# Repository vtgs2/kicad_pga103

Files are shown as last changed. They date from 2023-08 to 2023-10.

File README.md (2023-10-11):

# kicad_pga103

KiCAD Designs for PGA-103+ Preamplifier (LNA) intended for use in VHF / UHF Satellite Reception.  

This is a catchall repo for multiple designs and multiple variants.  
The variants will be based on physical size, enclosure dimensions, and specific features.  
This is a fluid repo that wil be changing as time allows to include updates for parts selection and user guide for how to configure for different bands.  

## Shut up and give me the board

Completed Designs:
- v2.0.0.0, rev-, Oct 2, 2023
- v2.1.X.0, rev-, Oct 2, 2023
- v2.2.X.0, rev-, Oct 2, 2023

#### Osh Park:
[v2.0.0.0, rev-](https://oshpark.com/shared_projects/KYiMNU72)  
[v2.1.X.0, rev-](https://oshpark.com/shared_projects/wypFvs1c)  
[v2.2.X.0, rev-](https://oshpark.com/shared_projects/yOYgdtt8)  

## Major Design Features

### Active Device
Primary active device is the popular [PGA-103+](https://www.minicircuits.com/WebStore/dashboard.html?model=PGA-103%2B).
Expect >20 dB Gain and <1.0 dB Noise Figure for both VHF and UHF bands.  

### Bias Options
Multiple biasing options via solder jumpers on the board.  
See board silkscreen for solder jumper settings for selecting the methods described below.

#### DC on Coax, +12V
The primary expected method for powering the board.  
This method routes DC power from the output RF connector to the internal voltage regulator for power conditioning, filtering, and biasing the amp.  
A bias-t will be required on the other end of the coax close to the radio.  
A custom Bias-T design may be added to this repo, but for now here are some COTS options:
- Minicircuits [ZDPLX-2150-S+](https://www.minicircuits.com/WebStore/dashboard.html?model=ZDPLX-2150-S%2B) where the Low Pass port is for DC. Be careful about current draw requirements if using long coax runs as this has a fairly low current limit of about 100mA.  Have succesfully used this on multiple compact systems in the past.
- Minicircuits [ZABT-2R15G+](https://www.minicircuits.com/WebStore/dashboard.html?model=ZABT-2R15G%2B). This Bias-T allows 3A of DC current and also includes ability to inject a 10 MHz reference signal (not needed for this specific preamp design, but might be useful for future projects for distributing REF oscillator signals to antenna mounted components such as downconverters).
- [Kuhne Electronic Bias-Ts](https://www.kuhne-electronic.com/funk/en/shop/industrial/prof-passive-compone/prof-bias-tees/).  Pricey, but work well. They offer N and SMA variants.

##### Lightning Arrestors
If using the DC on coax methods and if using lightning arrestors (you should be!), be sure to select arrestors that allow DC pass through.  I typically connect bias-ts directly to the lightning arrestors inside the enclosure on the 'equipment' side of the arrestor using barrel N or SMA connectors.

#### DC on Coax, Direct 5V
DC on coax can be routed to AVOID the onboard voltage regulator and directly bias the PGA-103+ device.  
This method may be suitable for SDRs that have built in Bias-Ts, such as the popular [RTL-SDR](https://www.rtl-sdr.com/buy-rtl-sdr-dvb-t-dongles/) that has a built in 4.5V bias-T.

#### External DC
This method does not interact with RF output connector and supplies power to the onboard voltage regulator.  
The supplied DC Voltage should be between 6V and 16V as measured at the board input pads (consider DC voltage drop if running long external power lines).  
The current mechanical designs for enclosure do not include penetrations for external power.  
If adding external power, feed through capacitors / EMI filters are recommended. Something like [this](https://www.digikey.com/en/products/detail/tusonix-a-subsidiary-of-cts-electronic-components/4400-034LF/2079728).

## Version Description
Versioning is inspired by MAJOR.MINOR.PATCH type versioning....but will also be breaking the rules for that on purpose.

Version Fields:  ENCLOSURE.FILTER.BAND.GAIN
##### ENCLOSURE:  
1.X.X.X  [1550Z101](https://www.digikey.com/en/products/detail/hammond-manufacturing/1550Z101/2268541)  
2.X.X.X  [AN-1301-A](https://www.digikey.com/en/products/detail/bud-industries/AN-1301-A/5804533)

Enclosure style essentially dictates the board outline.

##### FILTER Style:  
X.0.X.X  No Filter  
X.1.X.X  [RBP-XXX Filter](https://www.minicircuits.com/WebStore/dashboard.html?model=RBP-140%2B)  
X.2.X.X  [SBXP-XXX Filter](https://www.minicircuits.com/WebStore/dashboard.html?model=SXBP-140%2B)

##### BAND:   
X.X.0.X  Wideband  
X.X.1.X  VHF  
X.X.2.X  UHF  

Band selection depends on the filter selection and the choice of components for the bypass caps and bias-t inductors.

##### GAIN:   
X.X.X.0  Single Stage  
X.X.X.1  Dual Stage  

Curent completed designs only include the single gain stage preamplifiers.
Future designs may include a dual gain stage design for 'ultra-gain' type operation.

<!-- | Version | Enclosure  | Filter    | Description  | Design Complete |
| ------- | ---------- | --------- | ------------ | --------------- |
| 1.0.0   | 1550Z102   | False     |              | True |
| 1.1.X   | 1550Z102   | RBP-XXX   |              | True |
| 1.1.1   | 1550Z102   | RBP-140   | VHF Band     | True |
| 1.1.2    | 1550Z102   | RBP-440   | UHF Band     | True |
| 2.0.0.0 | AN-1301-A  | False     | Alt Encl: 1550Z104  | False |
| 2.1.X   | AN-1301-A  | RBP-XXX   |              | False |
| 2.1.1   | AN-1301-A  | RBP-140   | VHF Band     | False |
| 2.1.2   | AN-1301-A  | RBP-440   | UHF Band     | False |
| 2.2.X   | AN-1301-A  | SBXP-XXX  |              | False |
| 2.2.1   | AN-1301-A  | SBXP-140  | VHF Band     | False |
| 2.2.2   | AN-1301-A  | SBXP-440  | UHF Band     | False | -->

<!-- 

Multiple variants:
- Version 1: Unfiltered
- Version 2: Mini Circuits RBP-XXX Bandpass Filter
- Version 3: Mini Circuits SXBP-XXX Bandpass Filter
- Version 4: Dual Gain, RBP-XXX (Future)
- Version 5: Dual Gain, SXBP-XXX (Future) -->

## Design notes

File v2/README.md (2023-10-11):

# PGA-103+ Preamplifier, Version 2

Enclosure: AN-1301-A

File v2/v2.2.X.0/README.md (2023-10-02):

# PGA-103+ Preamplifier, Version 2.2.X.0

Enclosure: AN-1301-A  
Filter: SXBP-XXX  
Band: VHF or UHF  
Gain: Single Stage

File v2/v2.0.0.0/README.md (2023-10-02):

# PGA-103+ Preamplifier, Version 2.0.0.0

Enclosure: AN-1301-A  
Filter: None  
Band: Wideband  
Gain: Single Stage

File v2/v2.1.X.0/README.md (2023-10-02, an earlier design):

# PGA-103+ Preamplifier, Version 2.1.X.0

Enclosure: AN-1301-A  
Filter: RBP-XXX  
Band: VHF or UHF  
Gain: Single Stage

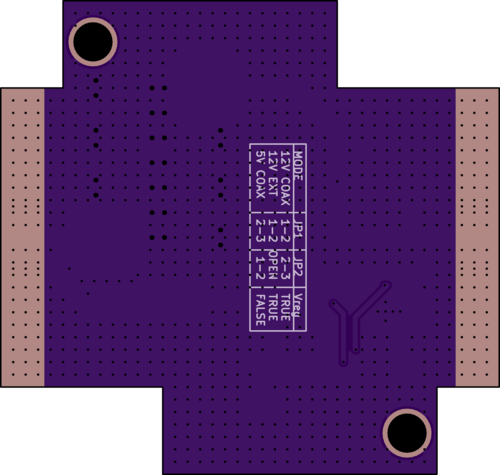
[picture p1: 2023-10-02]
v2/v2.2.X.0/rev-/osh_park_bottom_view.png

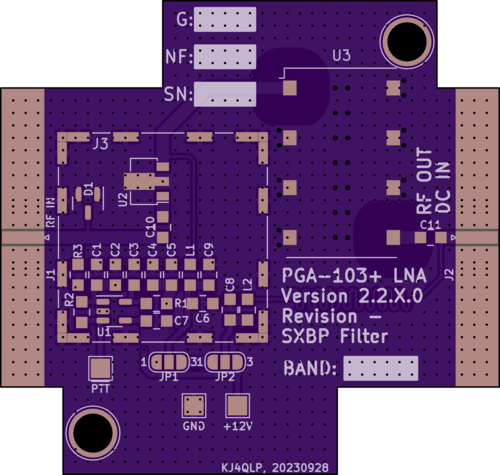
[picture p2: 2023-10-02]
v2/v2.2.X.0/rev-/osh_park_top_view.png

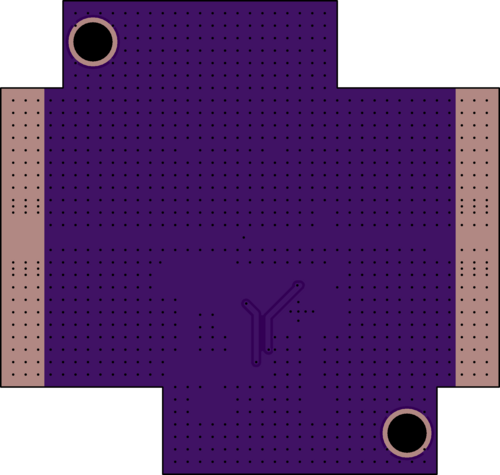
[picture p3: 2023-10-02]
v2/v2.0.0.0/rev-/osh_park_bottom_view.png

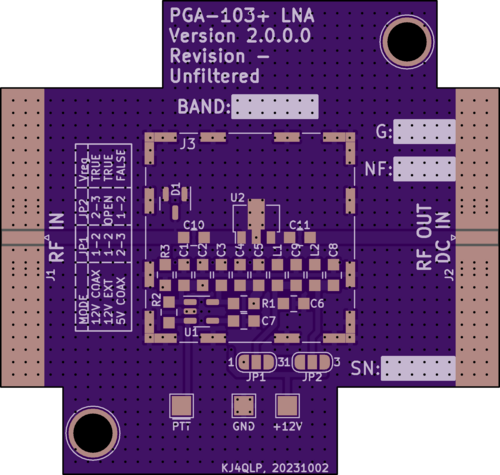
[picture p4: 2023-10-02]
v2/v2.0.0.0/rev-/osh_park_top_view.png

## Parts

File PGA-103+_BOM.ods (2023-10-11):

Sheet: MASTER_PGA-103
Supplier | Part # | Supplier Description | U/L | Qty | Unit Cost | Total Cost | LINK | Board ID | Comment | Order Status
Digikey | 3157-PGA-103+CT-ND | RF Amplifier IC CATV, Cellular, DBS, MMDS, PCS, WLAN, Wireless LAN 50MHz ~ 4GHz SOT-89 | ea | 10 | $2.63 | $26.30 | LINK (https://www.digikey.com/en/products/detail/mini-circuits/PGA-103/13680582?s=N4IgTCBcDaIAoHECCBaAjABgMwgLoF8g)
Digikey | 732-2486-ND | RF Shield Frame 0.827" (21.00mm) X 0.827" (21.00mm) Surface Mount | ea | 10 | $3.18 | $31.80 | LINK (https://www.digikey.com/en/products/detail/würth-elektronik/36103205/2337461)
Digikey | 1016-1874-1-ND | SPX3819M5-L-5-0/TR; Linear Voltage Regulator IC Positive Fixed 1 Output 500mA SOT-23-5; 5V | ea | 10 | $0.50 | $5.00 | LINK (https://www.digikey.com/en/products/detail/maxlinear-inc/SPX3819M5-L-5-0-TR/2472395)
Digikey | 3157-RBP-140+CT-ND | RBP-140+, 140MHz Center Frequency Band Pass RF Filter (Radio Frequency) 20MHz Bandwidth 3.5dB 8-SMD, No Lead | ea | 1 | $19.90 | $19.90 | LINK (https://www.digikey.com/en/products/detail/mini-circuits/RBP-140/13927413?s=N4IgTCBcDaIEoCEAKBaAjAFgAwgLoF8g) | V2.1.1.0
Digikey | 3157-RBP-440+CT-ND | RBP-440+, 440MHz Center Frequency Band Pass RF Filter (Radio Frequency) 60MHz Bandwidth 8-SMD, No Lead | ea | 1 | $18.56 | $18.56 | LINK (https://www.digikey.com/en/products/detail/mini-circuits/RBP-440/13928394?s=N4IgTCBcDaIEoCEAKBaALGgDCAugXyA) | V2.1.2.0
Minicircuits | SXBP-140+ | SXBP-140+, Lumped LC Band Pass Filter, 130 - 150 MHz, 50Ω | ea | 1 | $20.17 | $20.17 | LINK (https://www.minicircuits.com/WebStore/dashboard.html?model=SXBP-140%2B) | V2.2.1.0
Minicircuits | SXBP-425+ | SXBP-425+, Lumped LC Band Pass Filter, 410 - 440 MHz, 50Ω | ea | 1 | $22.70 | $22.70 | LINK (https://www.minicircuits.com/WebStore/dashboard.html?model=SXBP-425%2B) | V2.2.2.0
Digikey | 490-18663-1-ND | 10 µF ±10% 50V Ceramic Capacitor X5R 0805 (2012 Metric) | ea | 10 | $0.21 | $2.09 | LINK (https://www.digikey.com/en/products/detail/murata-electronics/GRM21BR61H106KE43L/10326316)
Digikey | 478-KGM21AR71H105JUCT-ND | 1 µF ±5% 50V Ceramic Capacitor X7R 0805 (2012 Metric) | ea | 25 | $0.22 | $5.48 | LINK (https://www.digikey.com/en/products/detail/kyocera-avx/KGM21AR71H105KU/3081236)
Digikey | 478-KGM21NR71H104JTCT-ND | 0.1 µF ±5% 50V Ceramic Capacitor X7R 0805 (2012 Metric) | ea | 100 | $0.04 | $3.78 | LINK (https://www.digikey.com/en/products/detail/kyocera-avx/KGM21NR71H104JT/929984)
Digikey | 478-08052C102J4Z2ACT-ND | 1000 pF ±5% 200V Ceramic Capacitor X7R 0805 (2012 Metric) | ea | 100 | $0.05 | $4.80 | LINK (https://www.digikey.com/en/products/detail/kyocera-avx/KAF21BR72D102JT/11238727) |  | For VHF
Digikey | 478-10451-1-ND | 330 pF ±5% 200V Ceramic Capacitor X7R 0805 (2012 Metric) | ea | 100 | $0.05 | $5.01 | LINK (https://www.digikey.com/en/products/detail/kyocera-avx/08052C331JAZ2A/6138434) |  | For UHF
Digikey | 13-RC0805FR-10100KLCT-ND | 100 kOhms ±1% 0.125W, 1/8W Chip Resistor 0805 (2012 Metric) Moisture Resistant Thick Film | ea | 100 | $0.01 | $1.27 | LINK (https://www.digikey.com/en/products/detail/yageo/RC0805FR-10100KL/13694085)
Digikey | 311-2.94CRCT-ND | 2.94 Ohms ±1% 0.125W, 1/8W Chip Resistor 0805 (2012 Metric) Moisture Resistant Thick Film | ea | 10 | $0.04 | $0.41 | LINK (https://www.digikey.com/en/products/detail/yageo/RC0805FR-072R94L/727716) |  | For 4.75V bias @ 84.9mA
Digikey | 311-1.50CRCT-ND | 1.5 Ohms ±1% 0.125W, 1/8W Chip Resistor 0805 (2012 Metric) Moisture Resistant Thick Film | ea | 100 | $0.02 | $2.27 | LINK (https://www.digikey.com/en/products/detail/yageo/RC0805FR-071R5L/727495) |  | to account for inductor resistance, 330nH
Digikey | 311-2.26CRTR-ND | 2.26 Ohms ±1% 0.125W, 1/8W Chip Resistor 0805 (2012 Metric) Moisture Resistant Thick Film | ea | 100 | $0.03 | $2.68 | LINK (https://www.digikey.com/en/products/detail/yageo/RC0805FR-072R26L/727681) |  | to account for inductor resistance, 220nH
Digikey | 490-5672-1-ND | 330 nH Unshielded Wirewound Inductor 310 mA 1.4Ohm Max 0805 (2015 Metric) | ea | 25 | $0.16 | $3.95 | LINK (https://www.digikey.com/en/products/detail/murata-electronics/LQW2BASR33J00L/2625457) |  | 1.4Ohm res, for VHF
Digikey | 490-5669-1-ND | FIXED IND 220NH 400MA 700MOHM SM | ea | 25 | $0.16 | $3.95 | LINK (https://www.digikey.com/en/products/detail/murata-electronics/LQW2BASR22J00L/2625454) |  | 0.7 Ohm, for UHF
Digikey | 377-2390-ND | Box Metal, Aluminum Natural Cover Included 2.520" L x 2.270" W (64.01mm x 57.66mm) X 1.378" (35.00mm) | ea | 6 | $7.10 | $42.60 | LINK (https://www.digikey.com/en/products/detail/bud-industries/AN-1301-A/5804533) | V2 | Bud industries alternative
Digikey | 36-909-ND | 4 Stud Lockwasher, Internal Tooth Lug Terminal Flat Connector | ea | 25 | $0.19 | $4.86 | LINK (https://www.digikey.com/en/products/detail/keystone-electronics/909/317250)
Digikey | ACX1165-ND | N Type Connector Receptacle, Female Socket 50 Ohms Panel Mount Solder | ea | 12 | $6.45 | $77.41 | LINK (https://www.digikey.com/en/products/detail/amphenol-rf/172117/1011842)
McMaster-Carr | 92196A110 | 18-8 Stainless Steel Socket Head Screw, 4-40 Thread Size, 1/2" Long | pk | 1 | $6.38 | $6.38 | LINK (https://www.mcmaster.com/92196A110/)
McMaster-Carr | 91841A005 | 18-8 Stainless Steel Hex Nut, 4-40 Thread Size | pk | 1 | $3.89 | $3.89 | LINK (https://www.mcmaster.com/91841A005/)
 |  |  |  |  |  | $0.00
 |  |  |  |  | Subtotal | $315.26
Digikey | HM180-ND | Box Metal, Aluminum Unpainted Cover Included 1.976" L x 1.780" W (51.19mm x 45.21mm) X 1.197" (30.40mm) | ea | 0 | $8.46 | $0.00 | LINK (https://www.digikey.com/en/products/detail/hammond-manufacturing/1550Z101/2268541) | V1 | 6 in stock
Digikey | HM181-ND | Box Metal, Aluminum Black Cover Included 1.976" L x 1.780" W (51.19mm x 45.21mm) X 1.197" (30.40mm) | ea | 0 | $12.05 | $0.00 | LINK (https://www.digikey.com/en/products/detail/hammond-manufacturing/1550Z101BK/2268542) | V1 | alternative to above, 12 in stock
Digikey | HM186-ND | Box Metal, Aluminum Unpainted Cover Included 2.535" L x 2.299" W (64.39mm x 58.39mm) X 1.394" (35.41mm) | ea | 0 | $9.39 | $0.00 | LINK (https://www.digikey.com/en/products/detail/hammond-manufacturing/1550Z104/2268547) | V2
Digikey | 501-1549-ND | Box Metal, Aluminum Unpainted Cover Included 1.500" L x 1.130" W (38.10mm x 28.70mm) X 0.880" (22.35mm) | ea | 0 | $9.99 | $0.00 | LINK (https://www.digikey.com/en/products/detail/pomona-electronics/3754/736549) |  | Pomona tiny box, Bias-T candidate
Digikey | ARF2999-ND | N Type Connector Receptacle, Male Pin 50 Ohms Panel Mount Solder | ea | 0 | $12.07 | $0.00 | LINK (https://www.digikey.com/en/products/detail/amphenol-rf/172260/4948205)

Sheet: digikey_upload
3157-PGA-103+CT-ND | RF Amplifier IC CATV, Cellular, DBS, MMDS, PCS, WLAN, Wireless LAN 50MHz ~ 4GHz SOT-89 | 10 | $2.63
732-2486-ND | RF Shield Frame 0.827" (21.00mm) X 0.827" (21.00mm) Surface Mount | 10 | $3.18
1016-1874-1-ND | SPX3819M5-L-5-0/TR; Linear Voltage Regulator IC Positive Fixed 1 Output 500mA SOT-23-5; 5V | 10 | $0.50
3157-RBP-140+CT-ND | RBP-140+, 140MHz Center Frequency Band Pass RF Filter (Radio Frequency) 20MHz Bandwidth 3.5dB 8-SMD, No Lead | 1 | $19.90
3157-RBP-440+CT-ND | RBP-440+, 440MHz Center Frequency Band Pass RF Filter (Radio Frequency) 60MHz Bandwidth 8-SMD, No Lead | 1 | $18.56
490-18663-1-ND | 10 µF ±10% 50V Ceramic Capacitor X5R 0805 (2012 Metric) | 10 | $0.21
478-KGM21AR71H105JUCT-ND | 1 µF ±5% 50V Ceramic Capacitor X7R 0805 (2012 Metric) | 25 | $0.22
478-KGM21NR71H104JTCT-ND | 0.1 µF ±5% 50V Ceramic Capacitor X7R 0805 (2012 Metric) | 100 | $0.04
478-08052C102J4Z2ACT-ND | 1000 pF ±5% 200V Ceramic Capacitor X7R 0805 (2012 Metric) | 100 | $0.05
478-10451-1-ND | 330 pF ±5% 200V Ceramic Capacitor X7R 0805 (2012 Metric) | 100 | $0.05
13-RC0805FR-10100KLCT-ND | 100 kOhms ±1% 0.125W, 1/8W Chip Resistor 0805 (2012 Metric) Moisture Resistant Thick Film | 100 | $0.01
311-2.94CRCT-ND | 2.94 Ohms ±1% 0.125W, 1/8W Chip Resistor 0805 (2012 Metric) Moisture Resistant Thick Film | 10 | $0.04
311-1.50CRCT-ND | 1.5 Ohms ±1% 0.125W, 1/8W Chip Resistor 0805 (2012 Metric) Moisture Resistant Thick Film | 100 | $0.02
311-2.26CRTR-ND | 2.26 Ohms ±1% 0.125W, 1/8W Chip Resistor 0805 (2012 Metric) Moisture Resistant Thick Film | 100 | $0.03
490-5672-1-ND | 330 nH Unshielded Wirewound Inductor 310 mA 1.4Ohm Max 0805 (2015 Metric) | 25 | $0.16
490-5669-1-ND | FIXED IND 220NH 400MA 700MOHM SM | 25 | $0.16
377-2390-ND | Box Metal, Aluminum Natural Cover Included 2.520" L x 2.270" W (64.01mm x 57.66mm) X 1.378" (35.00mm) | 6 | $7.10
36-909-ND | 4 Stud Lockwasher, Internal Tooth Lug Terminal Flat Connector | 25 | $0.19
ACX1165-ND | N Type Connector Receptacle, Female Socket 50 Ohms Panel Mount Solder | 12 | $6.45

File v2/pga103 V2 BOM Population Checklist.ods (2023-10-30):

Populated |  |  | V2.0.0.0, Unfiltered
1 | 2 | 3 | Value | Qnty | Cmp name | Ref | Note
 |  |  | 1.0uF | 2 | C | C1, C5
 |  |  | 0.1uF | 4 | C | C2, C3, C6, C7
 |  |  | 10uF | 1 | C | C4
 |  |  | 1000pF (VHF) / 330pF (UHF) | 4 | C | C8, C9, C10, C11 | Double Check VHF/UHF Selection
 |  |  | 330nH (VHF) / 220nH (UHF) | 2 | L | L1, L2 | Double Check VHF/UHF Selection
 |  |  | 10 | 1 | R_US | R1 | Double check value for desired bias point
 |  |  | 100k | 1 | R_US | R2
 |  |  | DNP | 1 | R_US | R3 | Optional Static Bleed, 1 Mohm
 |  |  | BAV99 | 1 | BAV99 | D1 | Optional ESD Protection
 |  |  | RFShield_TwoPieces | 1 | RFShield_TwoPieces | J3
 |  |  | SPX3819M5-L-5-0 | 1 | SPX3819M5-L-5-0 | U1
 |  |  | PGA-103 | 1 | PGA-103 | U2
Populated |  |  | V2.1.0.0, RBP-XXX Filter
1 | 2 | 3 | Value | Qnty | Cmp name | Ref | Note
 |  |  | 1.0uF | 2 | C | C1, C5
 |  |  | 0.1uF | 4 | C | C2, C3, C6, C7
 |  |  | 10uF | 1 | C | C4
 |  |  | 1000pF (VHF) / 330pF (UHF) | 4 | C | C8, C9, C10, C11 | Double Check VHF/UHF Selection
 |  |  | 330nH (VHF) / 220nH (UHF) | 2 | L | L1, L2 | Double Check VHF/UHF Selection
 |  |  | 10 | 1 | R_US | R1 | Double check value for desired bias point
 |  |  | 100k | 1 | R_US | R2
 |  |  | DNP | 1 | R_US | R3 | Optional Static Bleed, 1 Mohm
 |  |  | BAV99 | 1 | BAV99 | D1 | Optional ESD Protection
 |  |  | RFShield_TwoPieces | 1 | RFShield_TwoPieces | J3
 |  |  | SPX3819M5-L-5-0 | 1 | SPX3819M5-L-5-0 | U1
 |  |  | PGA-103 | 1 | PGA-103 | U2
 |  |  | RBP-140/440 | 1 | RBP-280 | U3 | Double Check VHF/UHF Selection
Populated |  |  | V2.2.0.0, SXBP-XXX Filter
1 | 2 | 3 | Value | Qnty | Cmp name | Ref | Note
 |  |  | 1.0uF | 2 | C | C1, C5
 |  |  | 0.1uF | 4 | C | C2, C3, C6, C7
 |  |  | 10uF | 1 | C | C4
 |  |  | 1000pF (VHF) / 330pF (UHF) | 4 | C | C8, C9, C10, C11 | Double Check VHF/UHF Selection
 |  |  | 330nH (VHF) / 220nH (UHF) | 2 | L | L1, L2 | Double Check VHF/UHF Selection
 |  |  | 10 | 1 | R_US | R1 | Double check value for desired bias point
 |  |  | 100k | 1 | R_US | R2
 |  |  | DNP | 1 | R_US | R3 | Optional Static Bleed, 1 Mohm
 |  |  | BAV99 | 1 | BAV99 | D1 | Optional ESD Protection
 |  |  | RFShield_TwoPieces | 1 | RFShield_TwoPieces | J3
 |  |  | SPX3819M5-L-5-0 | 1 | SPX3819M5-L-5-0 | U1
 |  |  | PGA-103 | 1 | PGA-103 | U2
 |  |  | SXBP-140/440 | 1 | SXBP-140 | U3 | Double Check VHF/UHF Selection

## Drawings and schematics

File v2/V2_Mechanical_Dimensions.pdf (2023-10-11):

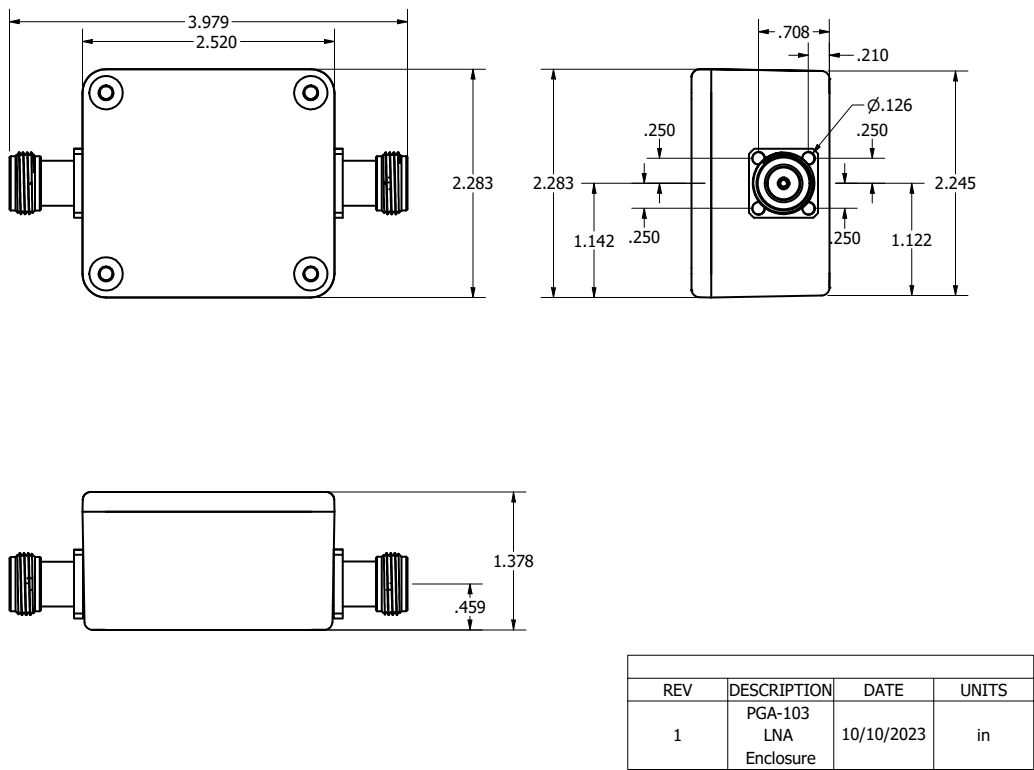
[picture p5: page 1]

REV | DESCRIPTION | DATE | UNITS
1 | PGA-103 LNA Enclosure | 10/10/2023 | in

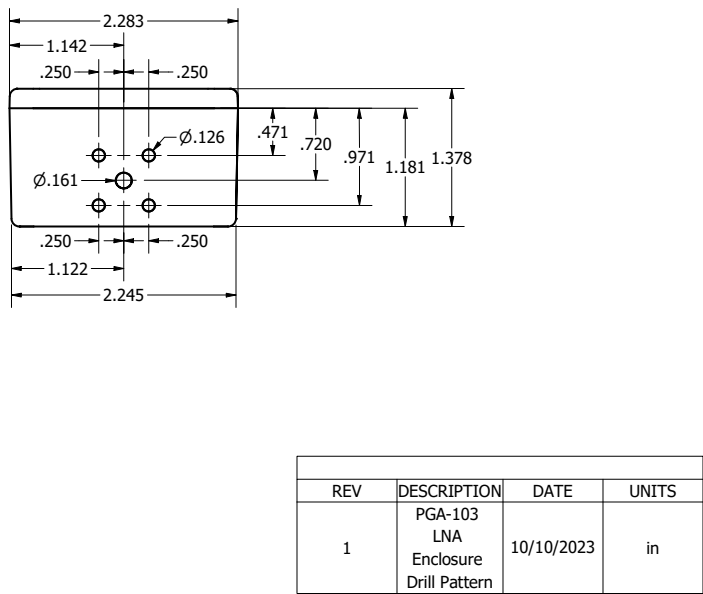
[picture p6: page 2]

REV | DESCRIPTION | DATE | UNITS
1 | PGA-103 LNA Enclosure Drill Pattern | 10/10/2023 | in

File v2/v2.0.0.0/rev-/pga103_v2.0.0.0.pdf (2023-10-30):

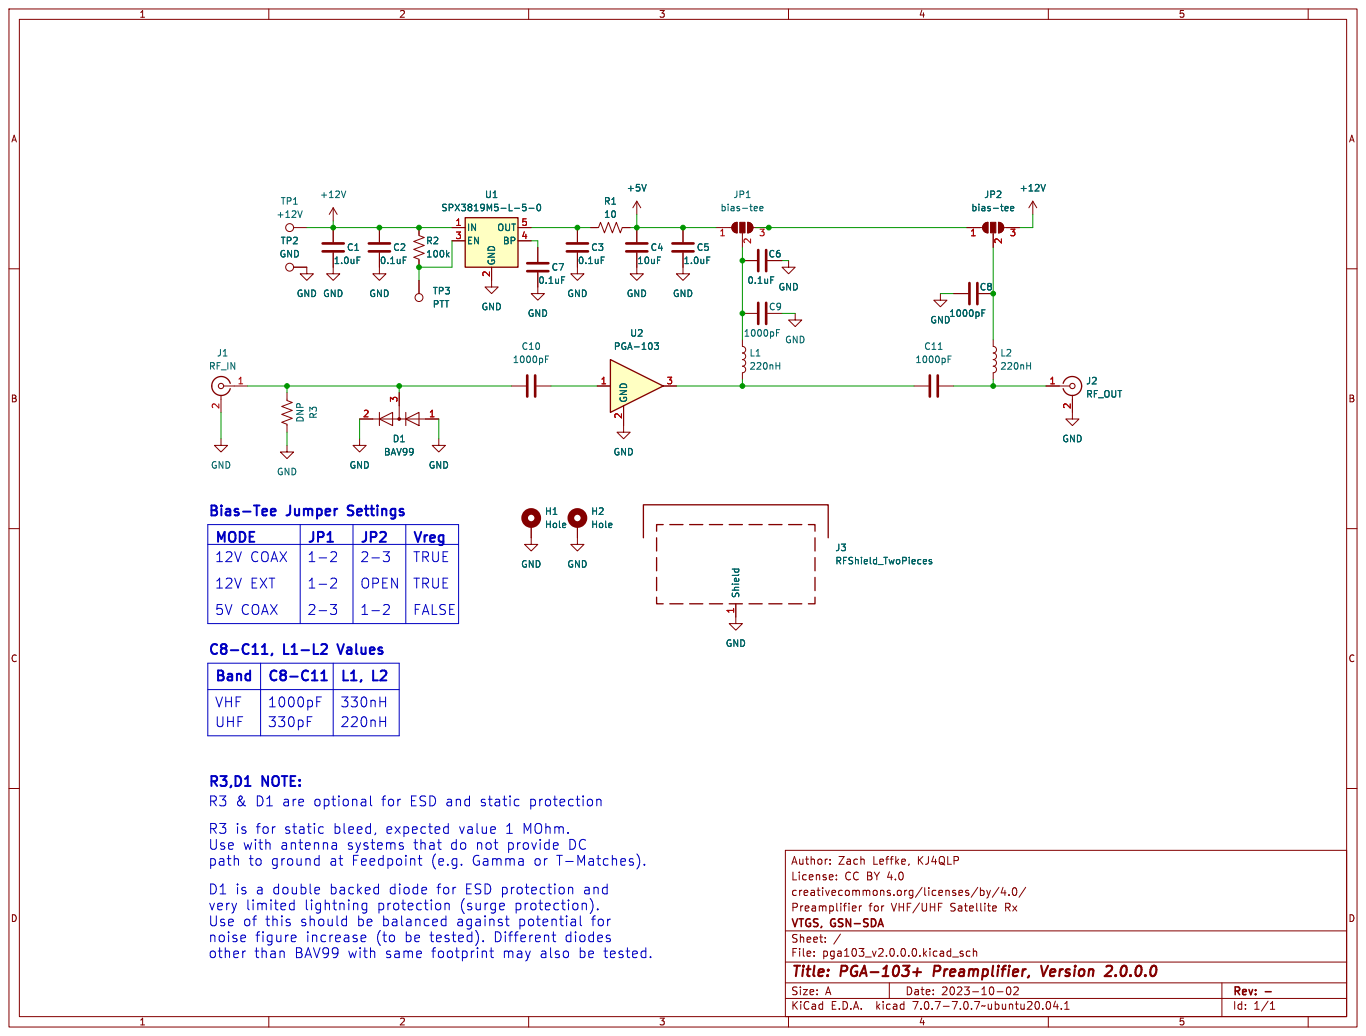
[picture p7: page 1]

bias-tee GND Band

2 EN 3 BP 4 OUT 5 U2 PGA-103

R3,D1 NOTE:
R3 is for static bleed, expected value 1 MOhm.
Use with antenna systems that do not provide DC
path to ground at Feedpoint (e.g. Gamma or T-Matches).

File: pga103_v2.0.0.0.kicad_sch Sheet: / VTGS, GSN-SDA

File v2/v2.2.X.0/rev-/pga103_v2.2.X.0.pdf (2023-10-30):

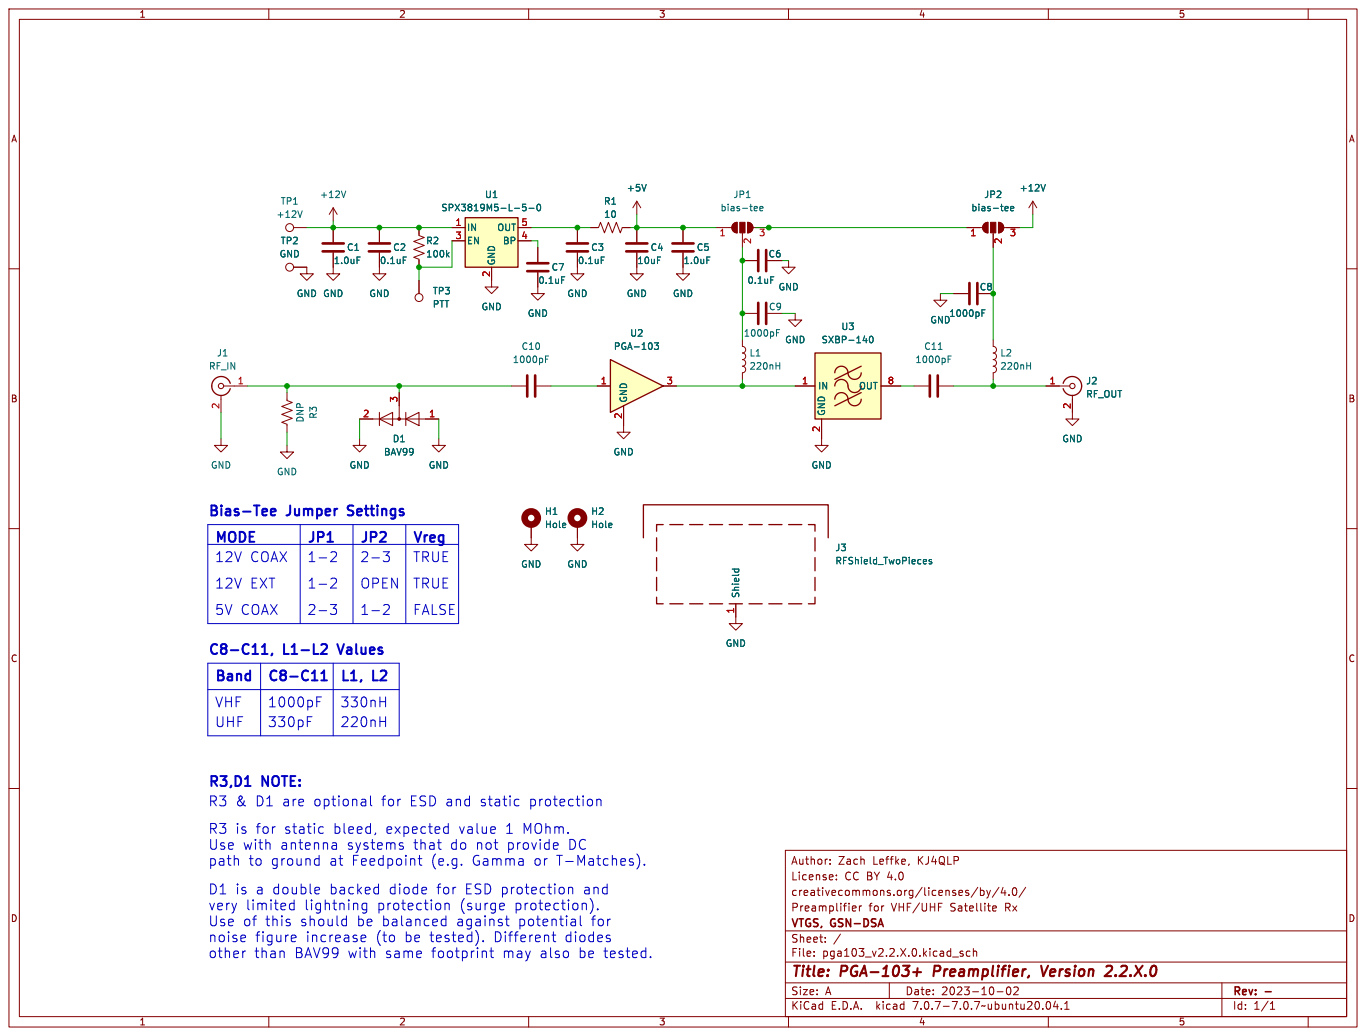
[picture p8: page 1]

2 EN 3 BP 4 OUT 5GND GND GND

2 OUT 8 GND GND GND

3 D1 BAV99 GND R3 DNP GND GND

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

File: pga103_v2.2.X.0.kicad_sch Sheet: / VTGS, GSN-DSA

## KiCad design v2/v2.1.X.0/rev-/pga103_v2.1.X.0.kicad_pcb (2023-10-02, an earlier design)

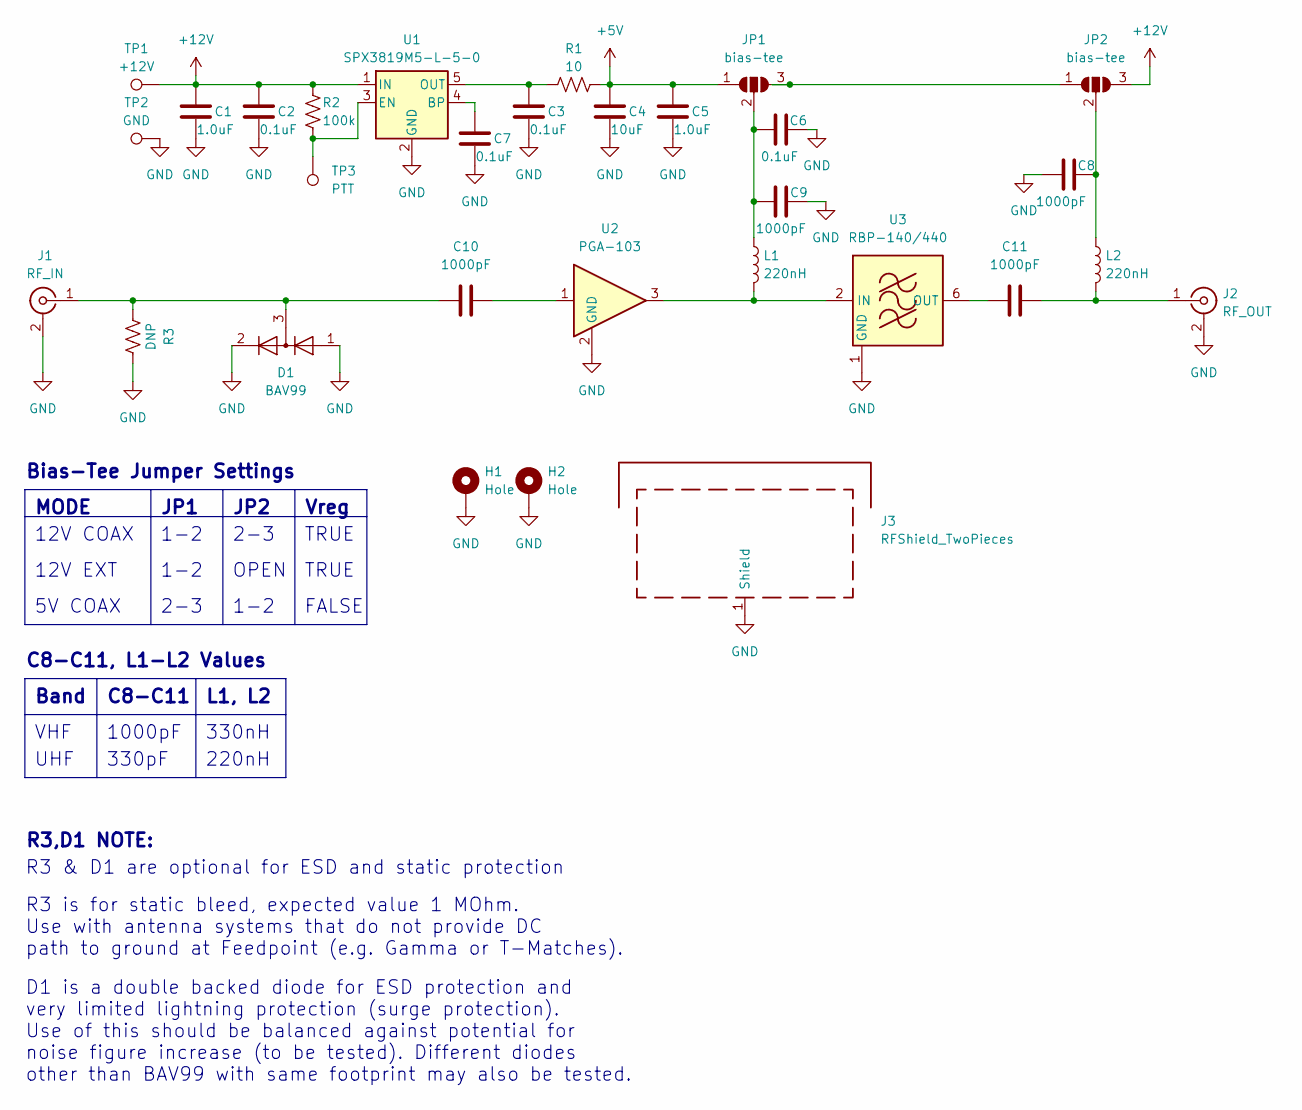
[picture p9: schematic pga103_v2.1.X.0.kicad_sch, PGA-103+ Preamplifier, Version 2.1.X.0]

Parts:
C1, C5: 1.0uF; 0805
C2, C3, C6, C7: 0.1uF; 0805
C4: 10uF; 0805
C8, C9, C10, C11: 1000pF; 0805
D1: BAV99; SOT-23
H1, H2: Hole; TestPoint_Plated_Hole_D4.0mm
J1: RF_IN; SMA_Samtec_SMA-J-P-X-ST-EM1_EdgeMount
J2: RF_OUT; SMA_Samtec_SMA-J-P-X-ST-EM1_EdgeMount
J3: RFShield_TwoPieces; Wuerth_36103205_20x20mm
JP1, JP2: bias-tee; SolderJumper-3_P1.3mm_Open_RoundedPad1.0x1.5mm_NumberLabels
L1, L2: 220nH; 0805
R1: 10; 0805
R2: 100k; 0805
R3: DNP; 0805
TP1: +12V; TestPoint_Pad_2.0x2.0mm
TP2: GND; TestPoint_Pad_2.0x2.0mm
TP3: PTT; TestPoint_Pad_2.0x2.0mm
U1: SPX3819M5-L-5-0; SOT-23-5
U2: PGA-103; SOT-89-3
U3: RBP-140/440; Mini-Circuits_GP731_LandPatternPL-176

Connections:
+5V: C4.2, C5.2, JP1.1 (A), R1.2
+12V: C1.2, C2.2, JP2.3 (B), R2.1, TP1.1, U1.1 (IN)
GND: C1.1, C2.1, C3.1, C4.1, C5.1, C6.1, C7.1, C8.2, C9.1, D1.1 (K), D1.2 (A), H1.1, H2.1, J1.2 (Ext), J2.2 (Ext), J3.1 (Shield), R3.2, TP2.1, U1.2 (GND), U2.2 (GND), U3.1 (GND), U3.3 (GND), U3.4 (GND), U3.5 (GND), U3.7 (GND), U3.8 (GND)
unnamed: C10.2, U2.1
unnamed: C10.1, D1.3 (K), J1.1 (In), R3.1
unnamed: C11.2, J2.1 (In), L2.2
unnamed: JP1.3 (B), JP2.1 (A)
unnamed: C6.2, C9.2, JP1.2 (C), L1.1
unnamed: C8.1, JP2.2 (C), L2.1
unnamed: C7.2, U1.4 (BP)
unnamed: R2.2, TP3.1, U1.3 (EN)
unnamed: C3.2, R1.1, U1.5 (OUT)
unnamed: L1.2, U2.3, U3.2 (IN)
unnamed: C11.1, U3.6 (OUT)

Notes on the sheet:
UHF
2-3
TRUE
R3 is for static bleed, expected value 1 MOhm. Use with antenna systems that do not provide DC path to ground at Feedpoint (e.g. Gamma or T-Matches).
330nH
D1 is a double backed diode for ESD protection and very limited lightning protection (surge protection). Use of this should be balanced against potential for noise figure increase (to be tested). Different diodes other than BAV99 with same footprint may also be tested.
330pF
C8-C11
VHF
OPEN
R3,D1 NOTE:
Bias-Tee Jumper Settings
JP1
R3 & D1 are optional for ESD and static protection
JP2
C8-C11, L1-L2 Values
12V COAX
1-2
Vreg
220nH
1000pF
MODE
5V COAX
Band
L1, L2
12V EXT
FALSE

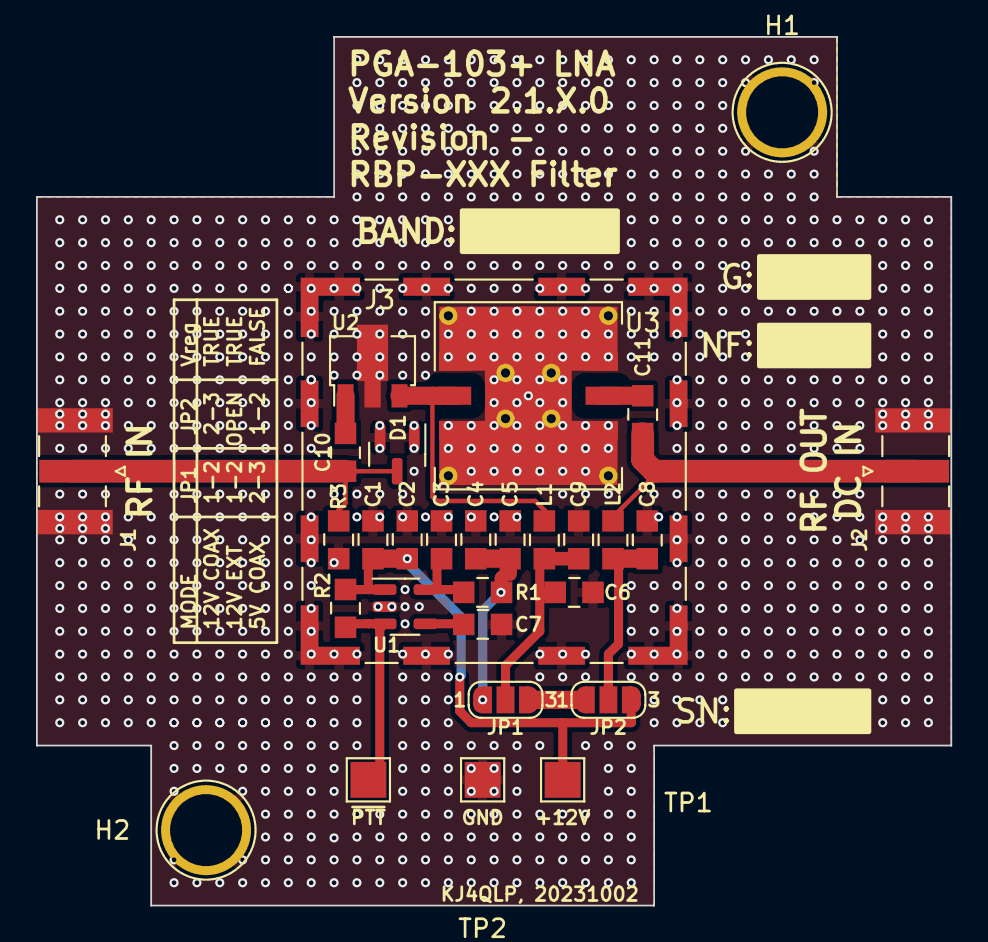
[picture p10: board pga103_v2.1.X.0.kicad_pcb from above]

Board: 2 copper layers, 50.8 x 48.3 mm, 30 parts (0 on the bottom side), 14 nets.

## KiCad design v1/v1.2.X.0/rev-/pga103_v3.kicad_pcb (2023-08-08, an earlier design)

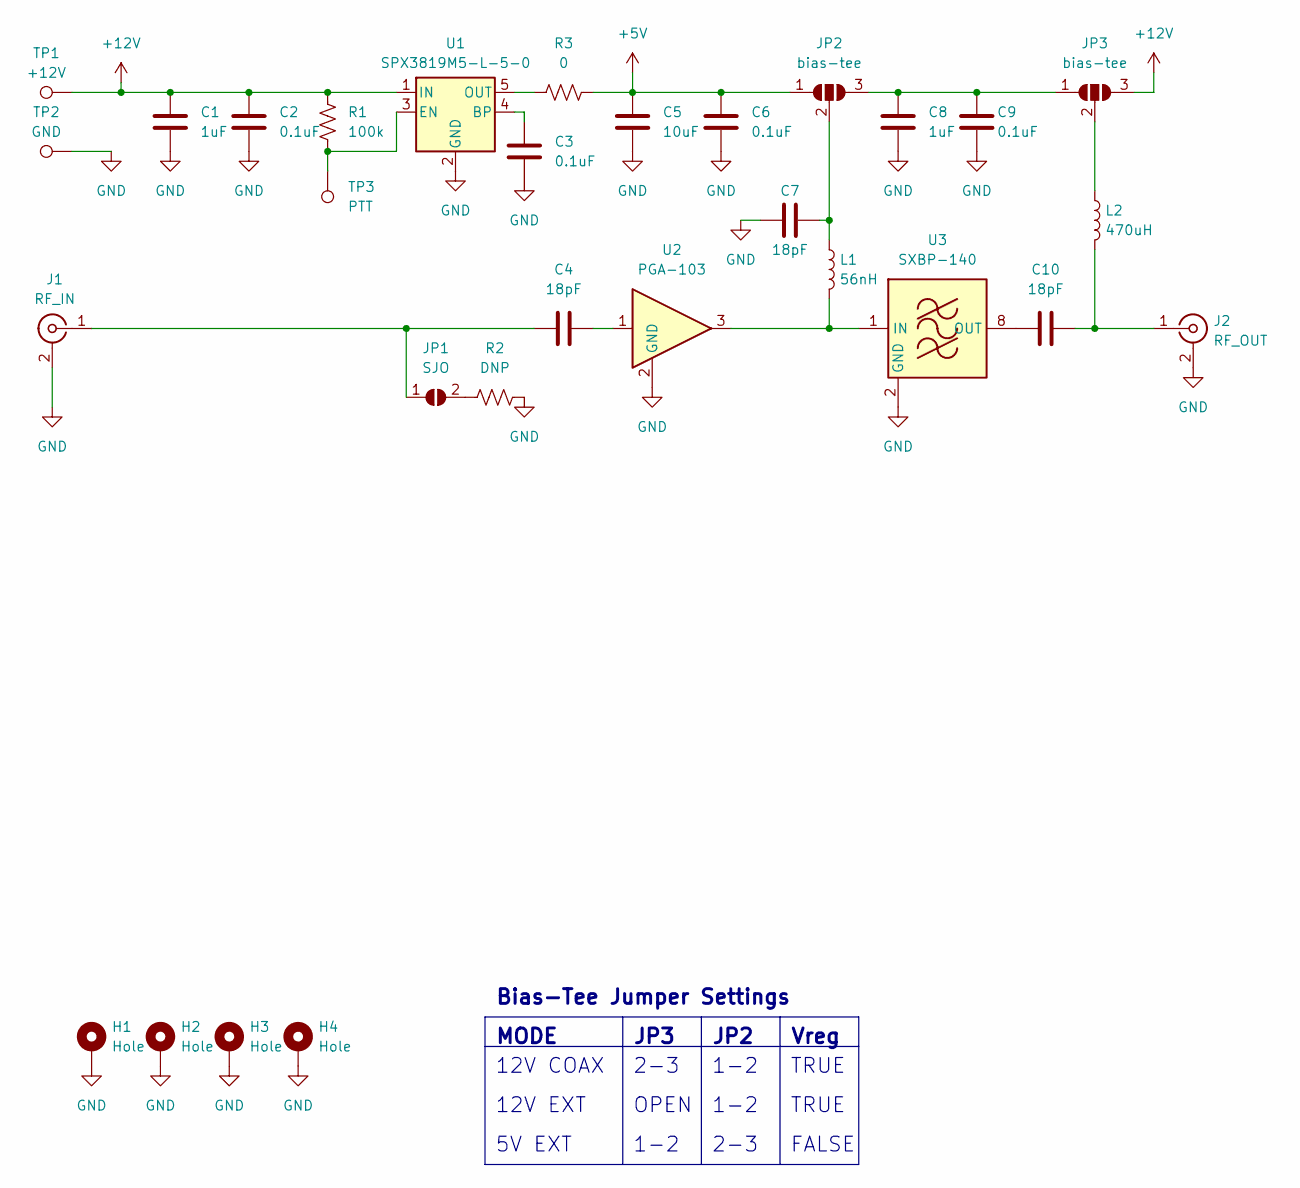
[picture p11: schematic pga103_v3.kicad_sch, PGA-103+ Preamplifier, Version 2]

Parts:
C1, C8: 1uF; 0805
C2, C3, C6, C9: 0.1uF; 0805
C4, C7, C10: 18pF; 0805
C5: 10uF; 0805
H1, H2, H3, H4: Hole; MountingHole_2.5mm_Pad_Via
J1: RF_IN; SMA_Samtec_SMA-J-P-X-ST-EM1_EdgeMount
J2: RF_OUT; SMA_Samtec_SMA-J-P-X-ST-EM1_EdgeMount
JP1: SJO; SolderJumper-2_P1.3mm_Open_RoundedPad1.0x1.5mm
JP2, JP3: bias-tee; SolderJumper-3_P1.3mm_Open_RoundedPad1.0x1.5mm_NumberLabels
L1: 56nH; 0805
L2: 470uH; 0805
R1: 100k; 0805
R2: DNP; 0805
R3: 0; 0805
TP1: +12V; TestPoint_Pad_2.0x2.0mm
TP2: GND; TestPoint_Pad_2.0x2.0mm
TP3: PTT; TestPoint_Pad_2.0x2.0mm
U1: SPX3819M5-L-5-0; SOT-23-5
U2: PGA-103; SOT-89-3
U3: SXBP-140; Mini-Circuits_HF1139_LandPatternPL-230

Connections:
+5V: C5.2, C6.2, JP2.1 (A), R3.2
+12V: C1.2, C2.2, JP3.3 (B), R1.1, TP1.1, U1.1 (IN)
GND: C1.1, C2.1, C3.1, C5.1, C6.1, C7.1, C8.1, C9.1, H1.1, H2.1, H3.1, H4.1, J1.2 (Ext), J2.2 (Ext), R2.2, TP2.1, U1.2 (GND), U2.2 (GND), U3.2 (GND), U3.3 (GND), U3.4 (GND), U3.5 (GND), U3.6 (GND), U3.7 (GND)
unnamed: C4.2, U2.1
unnamed: C4.1, J1.1 (In), JP1.1 (A)
unnamed: C10.2, J2.1 (In), L2.2
unnamed: JP1.2 (B), R2.1
unnamed: C8.2, C9.2, JP2.3 (B), JP3.1 (A)
unnamed: C7.2, JP2.2 (C), L1.1
unnamed: JP3.2 (C), L2.1
unnamed: C3.2, U1.4 (BP)
unnamed: R1.2, TP3.1, U1.3 (EN)
unnamed: R3.1, U1.5 (OUT)
unnamed: L1.2, U2.3, U3.1 (IN)
unnamed: C10.1, U3.8 (OUT)

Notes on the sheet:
2-3
TRUE
OPEN
Bias-Tee Jumper Settings
JP2
JP3
12V COAX
1-2
Vreg
MODE
5V EXT
12V EXT
FALSE

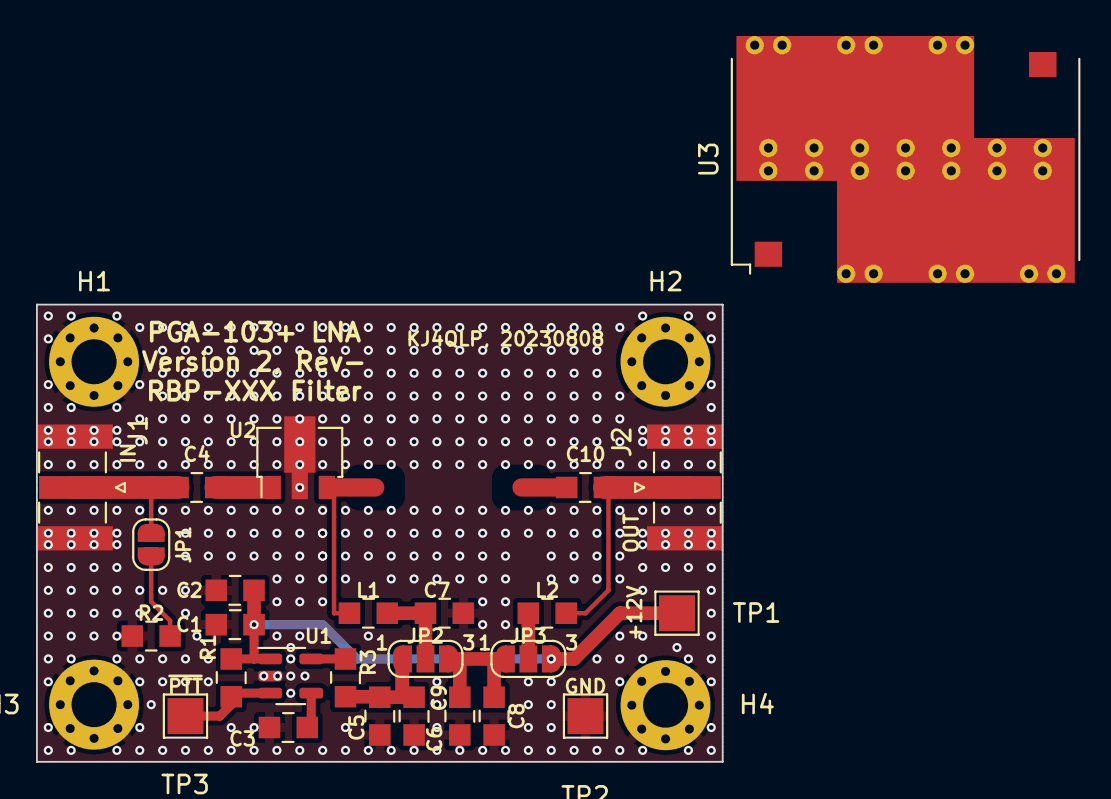
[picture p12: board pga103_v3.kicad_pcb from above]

Board: 2 copper layers, 38.1 x 25.4 mm, 30 parts (0 on the bottom side), 15 nets.

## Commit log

2023-08-08 multiple variants of pga-103 preamp design
    [bpf5_butter_130_150_tee_ideal.sch, bpf5_butter_130_150_tee_real.sch, bpf5_butter_390_450_pi_ideal.sch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]
2023-08-22 added pngs of board
2023-08-22 fixed silk screen for dimensions in V1
    [pga103_v1.kicad_pcb]
2023-09-21 updating board edge and adding shielding
    [pga103_v1.kicad_pcb, pga103_v1.kicad_sch]
2023-09-25 finalized V1 schematic and board
    [pga103_v1.kicad_pcb, pga103_v1.kicad_sch]
2023-09-25 forgot to save last commit.....
    [pga103_v1.kicad_pcb, pga103_v1.kicad_sch]
2023-09-25 initial commit of BOM, incomplete.
    [PGA-103+_BOM.ods]
2023-09-26 aded gitignore, about to rearrange for MAJOR.MINOR.PATCH versioning
    [PGA-103+_BOM.ods, pga103_v1.kicad_pcb, pga103_v2.kicad_pcb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]
2023-09-26 rearranged existing projects for new versioning scheme
    [PGA-103+_BOM.ods, pga103_v1.kicad_pcb, pga103_v1.kicad_sch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]
2023-10-02 adding updated versions.....close to ready for fab
    [PGA-103+_BOM.ods, pga103_v2.0.0.0.kicad_pcb, pga103_v2.0.0.0.kicad_sch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]
2023-10-02 added oshpark generated images of pcb.
    [PGA-103+_BOM.ods]
2023-10-02 added osh park images for v2 boards. PCBs at this commit submitted to Osh PArk
    [PGA-103+_BOM.ods]
2023-10-11 edited BOM, rearranged folders structure, added mechanical diagram for V2, updated readme.
    [PGA-103+_BOM.ods, pga103_v1.kicad_pcb, pga103_v1.kicad_sch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]
2023-10-30 added pdf of schematic, board population checklist, fixed typo in V2.0.0.0 title
    [pga103 V2 BOM Population Checklist.ods, pga103_v2.0.0.0.kicad_sch]

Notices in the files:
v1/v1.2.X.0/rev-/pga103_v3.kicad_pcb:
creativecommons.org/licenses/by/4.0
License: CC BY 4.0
